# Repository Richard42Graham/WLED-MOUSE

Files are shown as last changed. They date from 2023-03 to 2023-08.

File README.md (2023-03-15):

# WLED-Mouse

*Note: PCB is still very much work in progress*

PCB files for a for ESP32 board that can attach an INMP441 or ICS-43434 I²S microphone. It is intended to use together with [SR-WLED](https://github.com/atuline/WLED/) for mixing sound reactive and addressable LEDs together.

## I2S Digital Microphone information
The INMP441 is an omnidirectional digital microphone which communicates via I²S. It can be bought from a number of places, for example [Aliexpress](https://www.aliexpress.com/i/32962426410.html).

### Microphone hookup

Hookup instructions is taken from the [SR-WLED wiki](https://github.com/atuline/WLED/wiki/Digital-Microphone-Hookup#i2s-digital-audio).
| from INMP441, ICS-43434 | to ESP32 GPIO | |
| --- | --- | --- |
| L/R | Gnd | ground => left channel. Don't leave this pin unconnected!
| SD | 32 | serial data
| WS | 15 | left right clock
| SCK | 14 | serial clock
| VDD | 3.3V  | power don't use 5V!
| GND | Gnd | ground, 0V

## WLED setup

1. Fetch the binary from [SR-WLED](https://github.com/atuline/WLED/releases/latest) and flash to ESP32 board
1. Boot up WLED device and go to the "Sound setting" menu
2. Select `Generic I2S`
3. Reboot device
4. Have fun with sound reactive LEDs

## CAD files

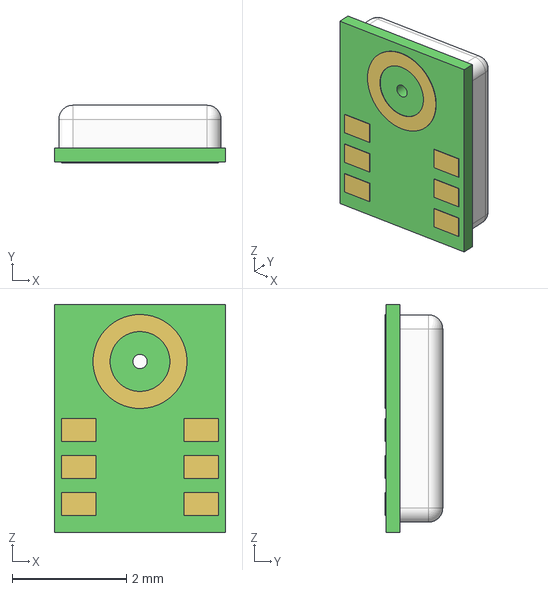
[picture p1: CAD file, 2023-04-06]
DMM-4026-B-I2S-R/DMM-4026-B-I2S-R.step
3.00 x 1.01 x 4.00 mm

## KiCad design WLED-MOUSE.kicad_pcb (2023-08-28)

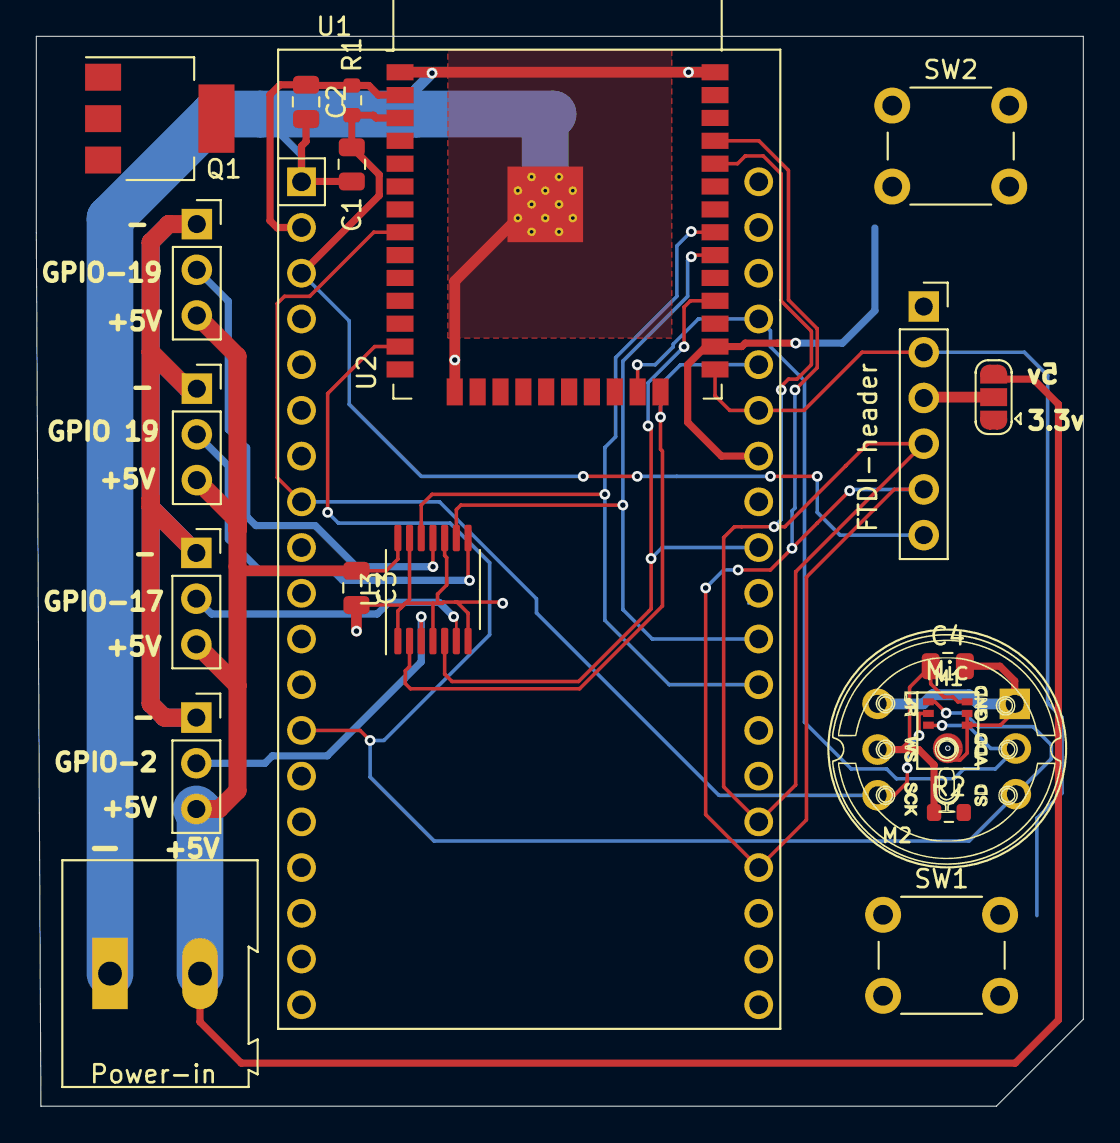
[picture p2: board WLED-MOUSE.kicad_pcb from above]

Board: 4 copper layers, 58.2 x 59.4 mm, 21 parts (0 on the bottom side), 22 nets.

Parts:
C1, C3, C4: C; C_0805_2012Metric
C2: 25uF; C_0805_2012Metric
J1: FTDI-header; PinSocket_1x06_P2.54mm_Vertical
J2: Power-in; TerminalBlock_Altech_AK300-2_P5.00mm
J4, J6, J7, J8: Pixel-strip; PinSocket_1x03_P2.54mm_Vertical
JP1: SolderJumper_3_Bridged12; SolderJumper-3_P1.3mm_Open_RoundedPad1.0x1.5mm
M1: INMP441; MIC_DMM-4026-B-I2S-R
M2: INMP441-TH; MIC_DMM-4026-B-I2S-R-TH
Q1: NDT3055L; SOT-223-3_TabPin2
R1, R2: R; R_0603_1608Metric
SW1, SW2: SW_MEC_5E; SW_PUSH_6mm
U1: ESP32-WROOM-32D; ESP32-DEVKITC-32D
U2: ESP32-WROOM-32D; ESP32-WROOM-32
U3: SN74LV4T125; TSSOP-14_4.4x5mm_P0.65mm

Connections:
+3.3V: C2.1, C4.1, JP1.1 (A), M1.7 (Vcc), M2.5 (Vcc), R1.1, R2.1, U1.2 (VDD), U2.2 (VDD)
+5V: C3.1, J2.2, J4.3, J6.3, J7.3, J8.3, JP1.3 (B), U3.14 (VCC)
/Button: SW2.1, U1.26 (IO4), U2.26 (IO4)
/GPIO-0: J1.2, SW1.1, U1.25 (IO0), U2.25 (IO0)
/LED-1: U1.24 (IO2), U2.24 (IO2), U3.2
/LED-2: U1.28 (IO17), U2.28 (IO17), U3.5
/LED-3: U1.30 (IO18), U2.30 (IO18), U3.9
/LED-4: U1.31 (IO19), U2.31 (IO19), U3.12
/Power Relay Pin: Q1.1 (G), U1.29 (IO5), U2.29 (IO5)
/Reset: C1.1, J1.6, R1.2, U1.3 (EN), U2.3 (EN)
/Rx: J1.4, U1.34 (RXD0/IO3), U2.34 (RXD0/IO3)
/SCK: M1.1 (SCK), M2.3 (SCK), U1.13 (IO14), U2.13 (IO14)
/SD: M1.2 (SD), M2.6 (SD), U1.8 (IO32), U2.8 (IO32)
/Tx: J1.5, U1.35 (TXD0/IO1), U2.35 (TXD0/IO1)
/WS: M1.3 (WS), M2.2 (WS), U1.23 (IO15), U2.23 (IO15)
GND: C1.2, C2.2, C3.2, C4.2, J1.1, J2.1, M1.4 (L/R), M1.5 (GND), M1.6 (GND), M2.1 (L/R), M2.4 (GND), Q1.3 (S), SW1.2, SW2.2, U1.1 (GND), U1.15 (GND), U1.38 (GND), U2.1 (GND), U2.15 (GND), U2.38 (GND), U2.39 (GND), U3.1, U3.4, U3.7 (GND), U3.10, U3.13
unnamed: J1.3, JP1.2 (C)
unnamed: J4.1, J6.1, J7.1, J8.1, Q1.2 (D)
unnamed: J4.2, U3.3
unnamed: J6.2, U3.6
unnamed: J7.2, U3.8
unnamed: J8.2, U3.11

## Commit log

2023-03-10 initial commit on WLED-MOUSE (a sound reactive WLED kit for labitat)
    [WLED-MOUSE.kicad_pcb, WLED-MOUSE.kicad_sch]
2023-03-16 added some parts, symbols and fooprints for a few things. allso 'touched grass' as this was recomended by a frined who said i was working too hard in linux. :3
    [WLED-MOUSE.kicad_pcb, WLED-MOUSE.kicad_sch]
2023-03-26 added some footprints for components
    [WLED-MOUSE.kicad_pcb, WLED-MOUSE.kicad_sch]
2023-04-04 added some more nice little bits
    [WLED-MOUSE.kicad_pcb, WLED-MOUSE.kicad_sch]
2023-04-06 wired up the schimatic for the level shifters.
    [WLED-MOUSE.kicad_sch]
2023-04-06 added the JLC PCB rules and settings, for eventual prodcution, also tried to add some of the stuff for the mic.
    [DMM-4026-B-I2S-R.step, WLED-MOUSE.kicad_pcb, WLED-MOUSE.kicad_sch]
2023-04-14 added footprint for the thought hole mic board, thing?
    [WLED-MOUSE.kicad_pcb, WLED-MOUSE.kicad_sch]
2023-04-27 started doing some more layout
    [WLED-MOUSE.kicad_pcb]
2023-05-01 checking its up to date,
    [WLED-MOUSE.kicad_pcb]
2023-06-16 started some routing and layout stuff
    [WLED-MOUSE.kicad_pcb]
2023-08-28 added GPIO names, to silk screen, to make life easier when using the board.
    [WLED-MOUSE.kicad_pcb, WLED-MOUSE.kicad_sch]
